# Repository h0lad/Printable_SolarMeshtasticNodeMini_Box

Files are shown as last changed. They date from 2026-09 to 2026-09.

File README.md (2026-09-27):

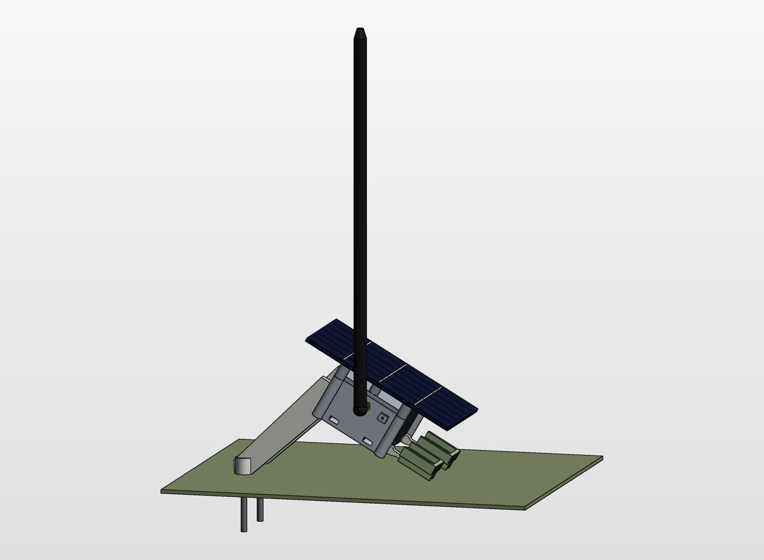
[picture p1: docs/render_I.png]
The box tilted on its two legs

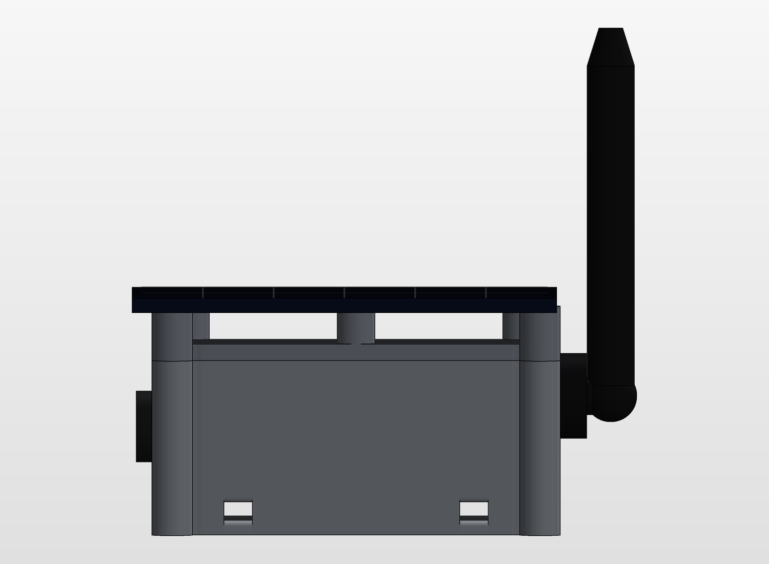
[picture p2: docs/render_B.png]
A section through the vent and the SMA bulkhead

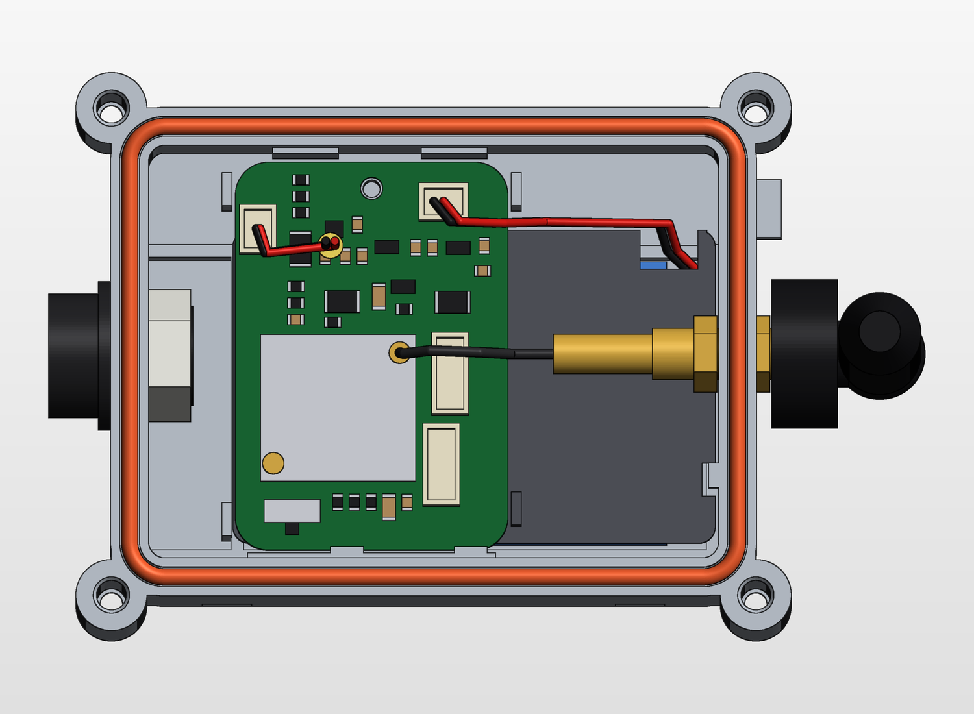
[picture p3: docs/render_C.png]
The top of the box, between the solar panel spacers

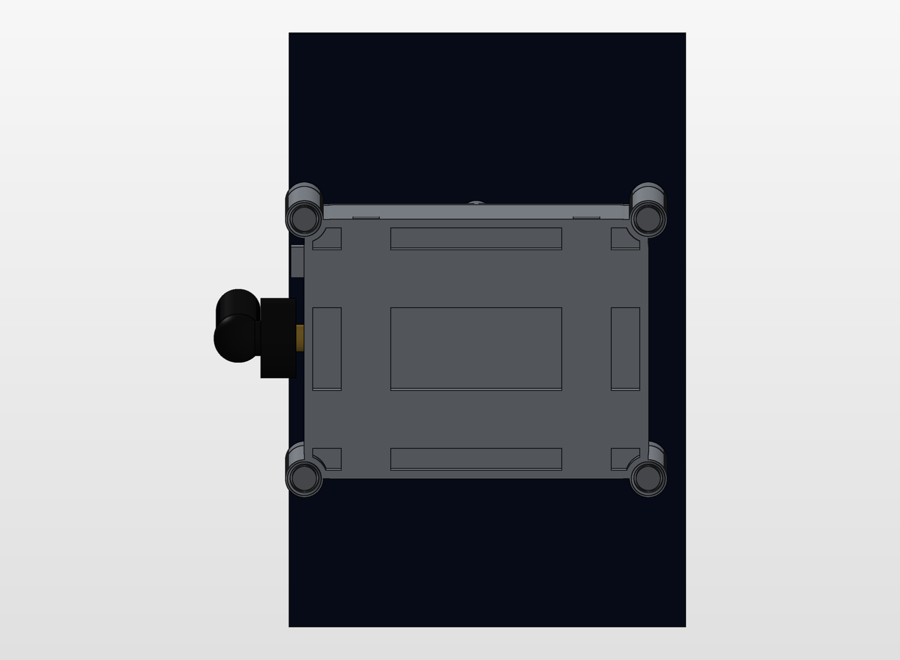
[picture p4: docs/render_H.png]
The underside, with the lashing tunnels and the floor relief


## Purpose

This box holds the SolarMeshtasticNodeMini node.

## Dimensions

The body is 78.2 x 59.2 x 40.5 mm, and the screw columns bring the footprint to 86.6 x 67.6 mm.

The solar panel and its spacers add 11 mm.

The inner cavity is 69 x 50 x 28 mm, and the vent chamber occupies x 59 to 69.

## Components to buy

- LiPo 103450 with a JST-PH lead, or LiPo 852040 with the adapter tray
- SMA bulkhead to U.FL, nose up to 20 mm, cable at least 90 mm
- ePTFE vent plug, thread 12 mm diameter and 10 mm long, head up to 20 mm, with its plastic nut
- Solar panel up to 135 x 90 mm, glued to the spacers with MS polymer
- 2 mm silicone O-ring cord, about 260 mm
- 4 M3x40 A4 screws, fitted from below, captive in a 2.7 mm neck, into 4 heat set inserts with a
  4.0 mm bore, 7 mm deep
- 1 M2.5x6 screw for the PCB, with a 2.1 mm pilot
- Cable ties 5 x 1.5 mm, or cord up to 3 mm, for the lashing tunnels

## Wind

The tipping speed comes from `tools/stability.py`. The stone sits in the ballast trays.

| setup | tips at | for reference |
|---|---|---|
| bare | 12.1 m/s | 44 km/h |
| 1 kg of stone in the trays | 14.5 m/s | 52 km/h |
| 2 kg of stone in the trays | 16.4 m/s | 59 km/h |

## Checks

The tools in `tools/` prove the numbers in this file. They need FreeCAD 1.0 with gmsh and ccx, and
every one of them writes a `.json` report beside itself.

| tool | what it proves |
|---|---|
| `design_rules.py` | the wall thickness, the holes, the gaps, the shell count, the build volume, and the collisions |
| `tolerance_mc.py` | every fit that has to go together, by Monte Carlo |
| `montage_simulation.py` | every step of the build order, over the full insertion travel |
| `clearance_probe.py` | the free radius around every fastener and nut |
| `stability.py` | the tipping speed, the hold-down force and the ballast mass |
| `thermal_lumped.py` | the internal temperature in the sun |
| `integrity_check.py` | the committed STEP files against a fresh run of the macro |

Run each one from `tools/`, as its docstring says.

## License

CERN Open Hardware Licence Version 2 - Strongly Reciprocal

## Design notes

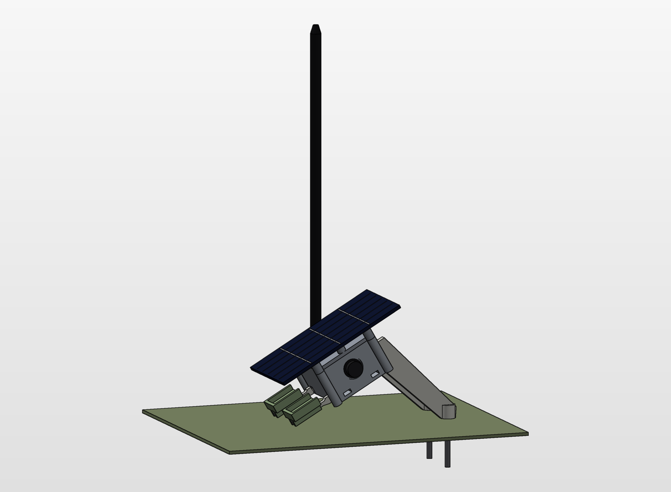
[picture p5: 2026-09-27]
docs/render_J.png

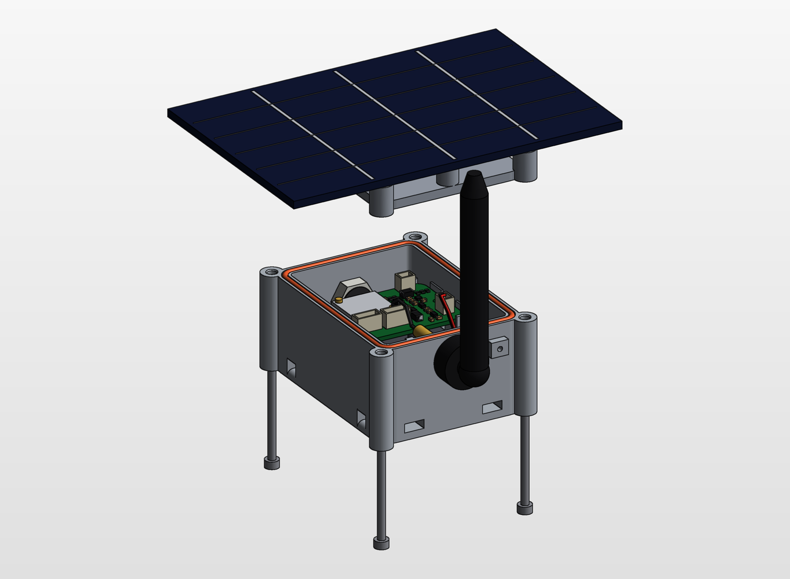
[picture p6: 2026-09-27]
docs/render_A.png

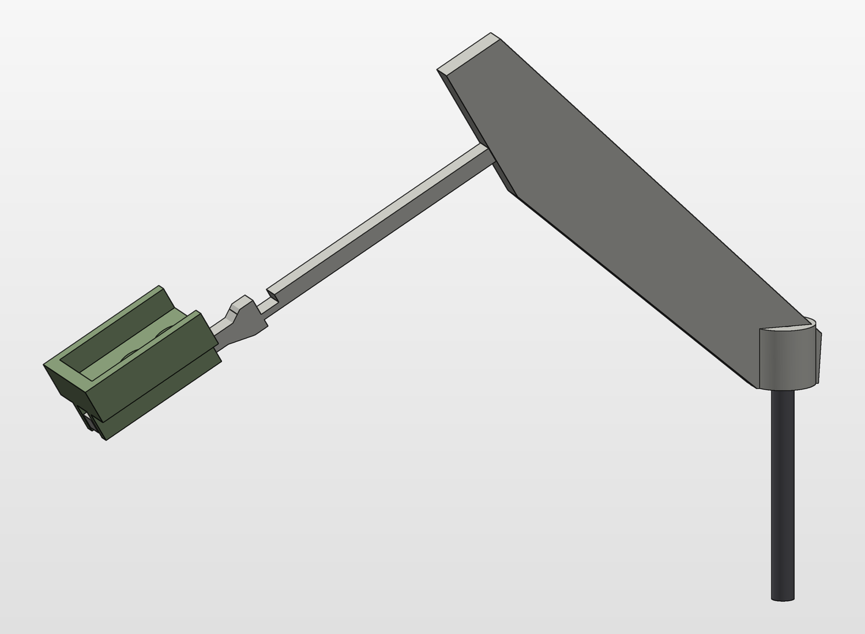
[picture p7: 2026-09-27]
docs/render_stand_fit.png

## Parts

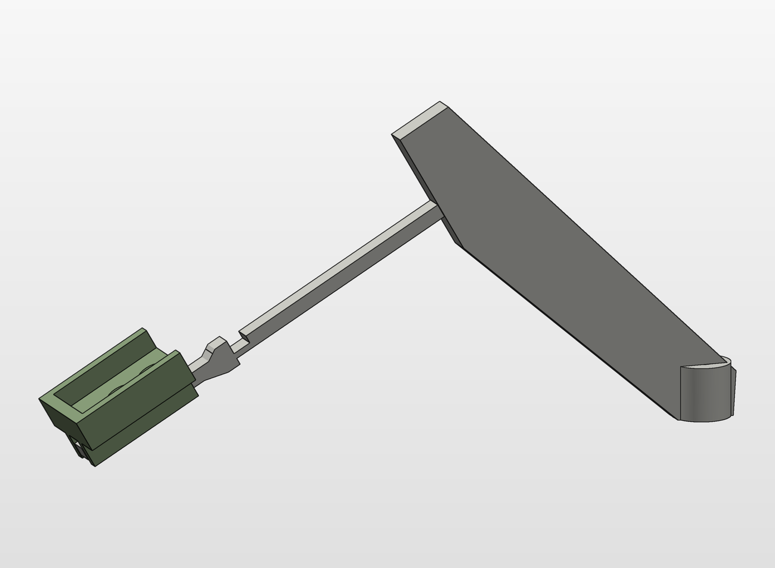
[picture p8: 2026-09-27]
docs/render_stand_parts.png

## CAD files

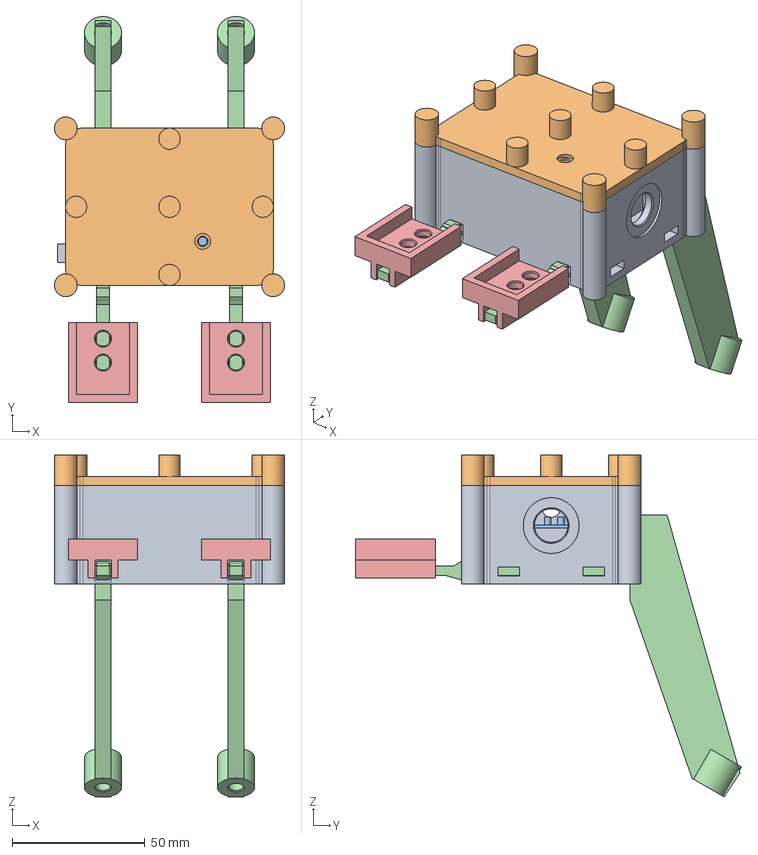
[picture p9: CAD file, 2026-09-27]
steps_stl/SolarMeshtasticNodeMini_assembly.step
86.6 x 145.2 x 128.6 mm

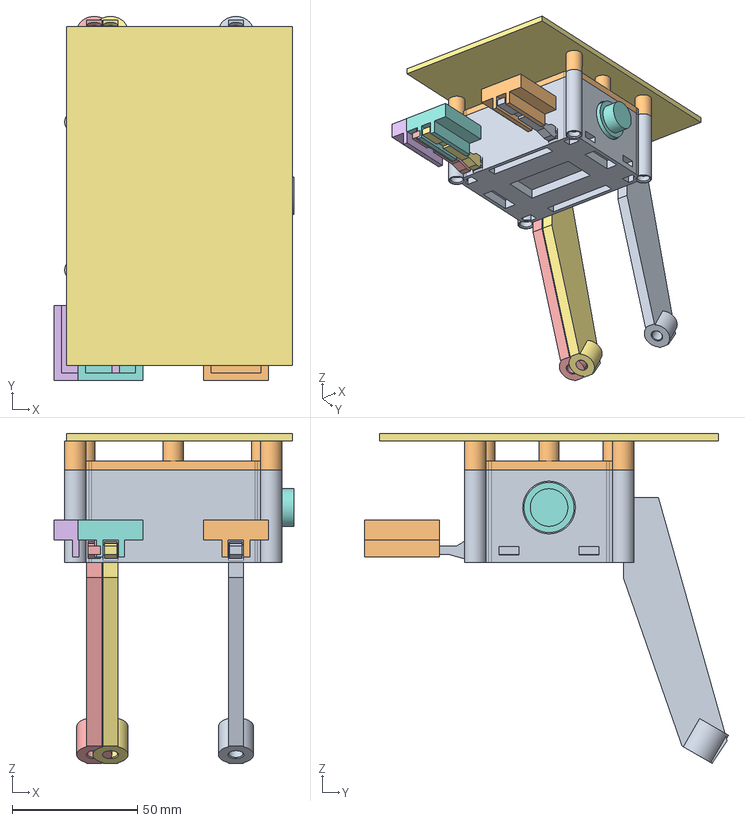
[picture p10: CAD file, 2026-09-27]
freecad/SolarMeshtasticNodeMini_Enclosure.FCStd
95.6 x 145.2 x 131.6 mm
base
lid
battery_plate
adapter_852040
stand_leg_x2
stand_tray_x2
stand_leg_1
stand_tray_1
stand_leg_2
stand_tray_2
PCB_dummy
parts_dummy
LiPo_103450_dummy
LiPo_852040_dummy
panel_135x90_dummy
vent_plug_dummy
vent_nut_dummy

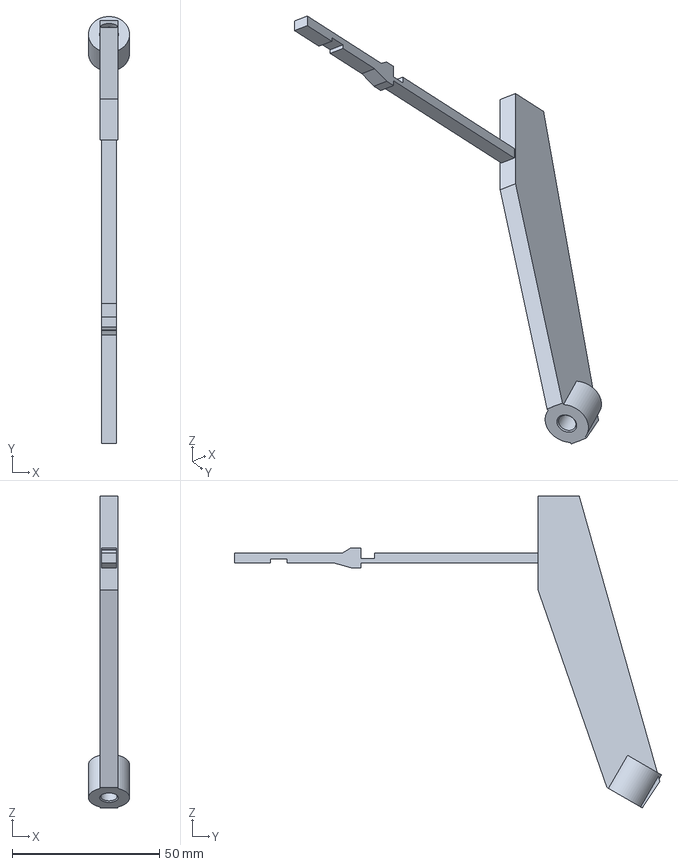
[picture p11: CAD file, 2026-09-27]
steps_stl/SolarMeshtasticNodeMini_stand_leg_x2.step
14.0 x 145.2 x 106.1 mm

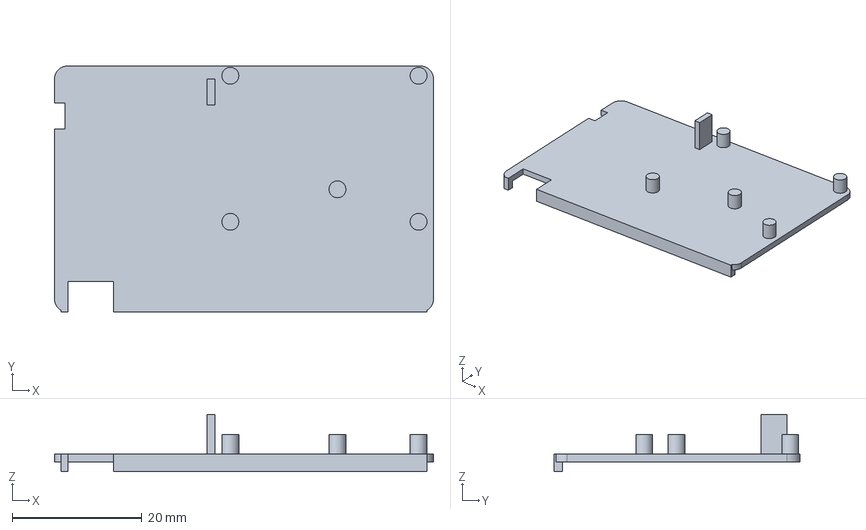
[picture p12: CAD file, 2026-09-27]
steps_stl/SolarMeshtasticNodeMini_battery_plate.step
58.4 x 37.9 x 8.79 mm

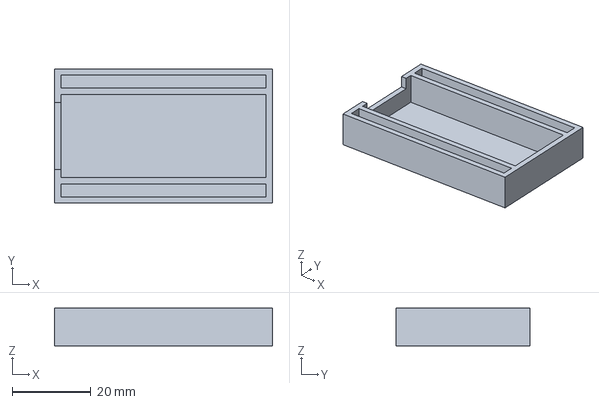
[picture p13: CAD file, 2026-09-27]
steps_stl/SolarMeshtasticNodeMini_adapter_852040.step
55.2 x 34.0 x 9.50 mm

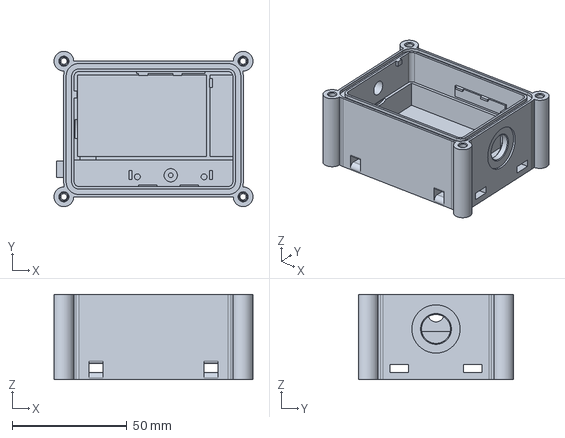
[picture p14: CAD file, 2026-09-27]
steps_stl/SolarMeshtasticNodeMini_base.step
86.6 x 67.6 x 37.0 mm

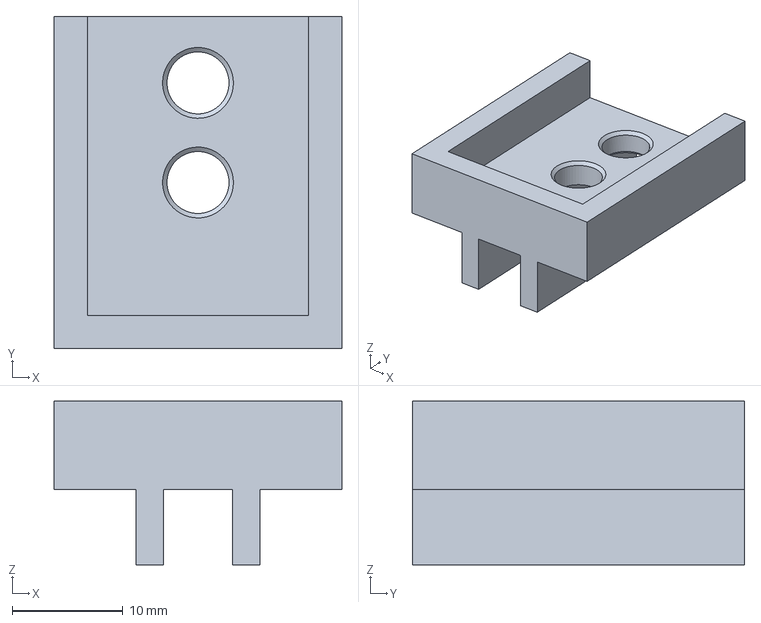
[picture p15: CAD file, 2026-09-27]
steps_stl/SolarMeshtasticNodeMini_stand_tray_x2.step
26.0 x 30.0 x 14.8 mm

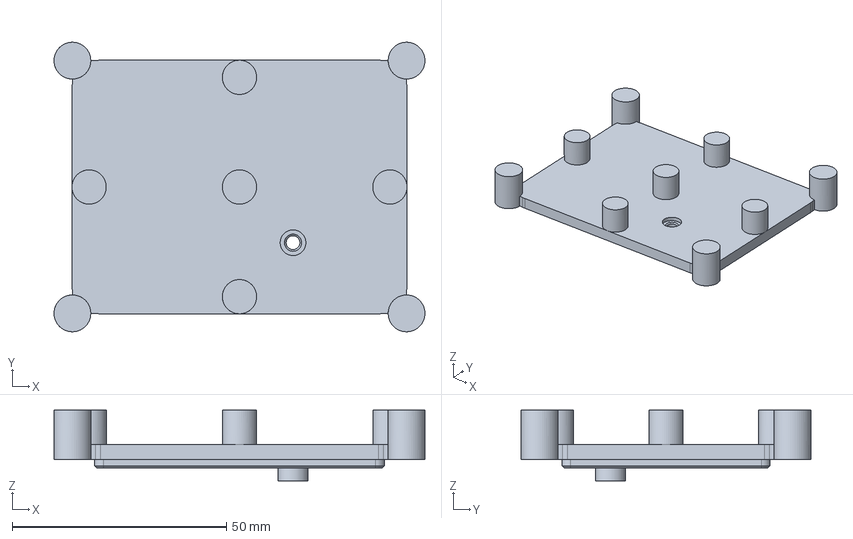
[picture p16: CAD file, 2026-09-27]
steps_stl/SolarMeshtasticNodeMini_lid.step
86.6 x 67.6 x 16.5 mm

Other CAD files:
steps_stl/SolarMeshtasticNodeMini_adapter_852040.stl
steps_stl/SolarMeshtasticNodeMini_base.stl
steps_stl/SolarMeshtasticNodeMini_battery_plate.stl
steps_stl/SolarMeshtasticNodeMini_lid.stl
steps_stl/SolarMeshtasticNodeMini_stand_leg_x2.stl
steps_stl/SolarMeshtasticNodeMini_stand_tray_x2.stl

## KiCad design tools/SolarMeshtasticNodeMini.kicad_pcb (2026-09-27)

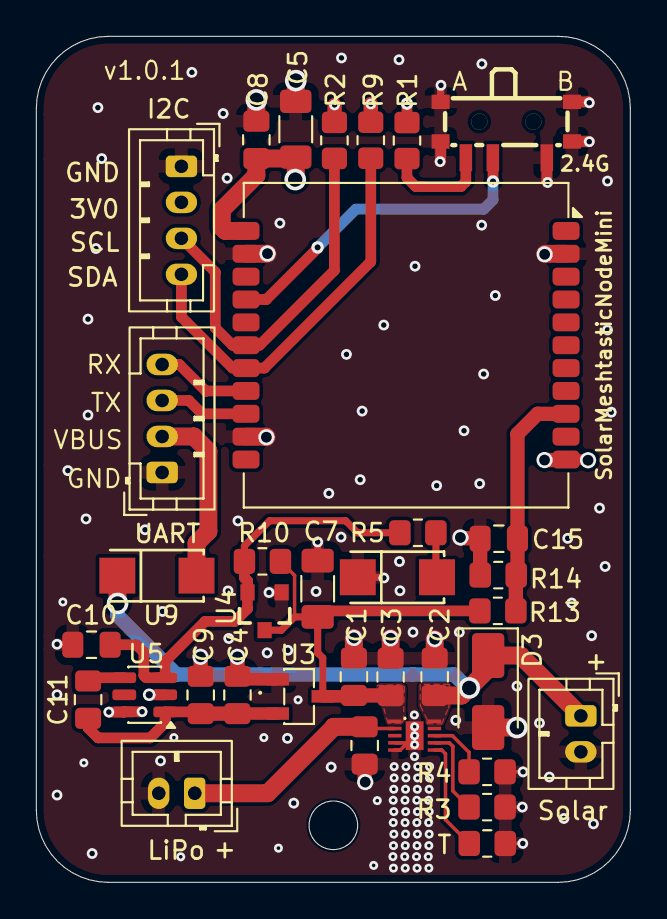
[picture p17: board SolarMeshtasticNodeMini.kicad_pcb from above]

Board: 4 copper layers, 33.0 x 47.0 mm, 36 parts (0 on the bottom side), 20 nets.

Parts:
C1, C4: 4.7uF; C_0805_2012Metric_Pad1.18x1.45mm_HandSolder
C2, C6, C9, C10: 1uF; C_0805_2012Metric_Pad1.18x1.45mm_HandSolder
C3: 10uF; C_0805_2012Metric_Pad1.18x1.45mm_HandSolder
C5: 47uF; R_1206_3216Metric_Pad1.30x1.75mm_HandSolder
C7: 1uF; C_1206_3216Metric_Pad1.33x1.80mm_HandSolder
C8, C15: 100nF; C_0805_2012Metric_Pad1.18x1.45mm_HandSolder
C11: 1nF; C_0805_2012Metric_Pad1.18x1.45mm_HandSolder
D3: SMAJ14A; D_SMA
H1: MountingHole; MountingHole_2.7mm_M2.5_ISO7380
J2: Conn_01x02_Socket; JST_PH_B2B-PH-K_1x02_P2.00mm_Vertical
J3, J5: Conn_01x04_Socket; JST_PH_B4B-PH-K_1x04_P2.00mm_Vertical
J4: Conn_01x02_Pin; JST_PH_B2B-PH-K_1x02_P2.00mm_Vertical
R1, R2, R9: 10k; R_0805_2012Metric_Pad1.20x1.40mm_HandSolder
R3, R10: 100k; R_0805_2012Metric_Pad1.20x1.40mm_HandSolder
R4: 360; R_0805_2012Metric_Pad1.20x1.40mm_HandSolder
R5: 470; R_0805_2012Metric_Pad1.20x1.40mm_HandSolder
R6: MF11-103; R_0805_2012Metric_Pad1.20x1.40mm_HandSolder
R13, R14: 1M; R_0805_2012Metric_Pad1.20x1.40mm_HandSolder
SW1: SSSS811101; SW-SMD_SSSS811101
SW2: SW_Push; SMA_L4.3-W2.6-LS5.1-RD
U1: BQ25185; SON40P220X200X80-11N
U2: HT-CT62; Heltec_HT-CT62
U3: HE9073A30MR; SOT-23-3_L2.9-W1.6-P1.90-LS2.8-BR-CW
U4: APX803L05-32SA-7; SOT23-3
U5: TPS22917DBV; SOT-23-6
U9: SS26_C5350986; SMA_L4.3-W2.6-LS5.1-RD

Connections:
+3V0: C5.2, C8.2, J5.2, R1.2, R2.2, R9.2, U2.11 (EN), U2.12 (VDD), U5.6 (VOUT)
/ADC_LOAD: C15.1, R13.2, R14.1, U2.9 (GPIO1)
/ESP32_BOOTLOADER_MODE_1: SW1.2, U2.15 (GPIO9)
/I2C_SCL: J5.3, R2.1, U2.17 (GPIO18_DN)
/I2C_SDA: J5.4, R9.1, U2.18 (GPIO19_DP)
/U_RX: J3.4, U2.19 (GPIO20_RXD)
/U_TX: J3.3, U2.20 (GPIO21_TXD)
/VBUS: C2.2, D3.1 (A1), J2.1, U1.10 (IN), U9.1 (K)
/VLIPO: C6.1, J4.1, U1.2 (BAT)
/VLOAD: C1.1, C3.2, C7.2, R10.1, R13.1, U1.1 (SYS), U3.2 (VIN), U4.3 (Vcc)
/VOUT: C4.1, C9.1, C11.1, U3.3 (VOUT), U5.1 (VIN)
/nReset: C10.2, R5.2, R10.2, U4.2 (nReset), U5.3 (ON)
GND: C1.2, C2.1, C3.1, C4.2, C5.1, C6.2, C7.1, C8.1, C9.2, C10.1, C15.2, D3.2 (A2), J2.2, J3.1, J4.2, J5.1, R3.2, R4.2, R6.2, R14.2, SW1.1, SW1.4, SW1.5, SW1.6, SW1.7, SW2.1, U1.4 (/CE), U1.5 (GND), U1.11 (GND), U2.2 (GND), U2.13 (GND), U2.21 (GND), U3.1 (GND), U4.1 (GND), U5.2 (GND)
unnamed: J3.2, U9.2 (A)
unnamed: R1.1, SW1.3
unnamed: R5.1, SW2.2
unnamed: R3.1, U1.7 (ILM/VSET)
unnamed: R4.1, U1.8 (ISET)
unnamed: R6.1, U1.6 (TS/MR)
unnamed: C11.2, U5.4 (CT)

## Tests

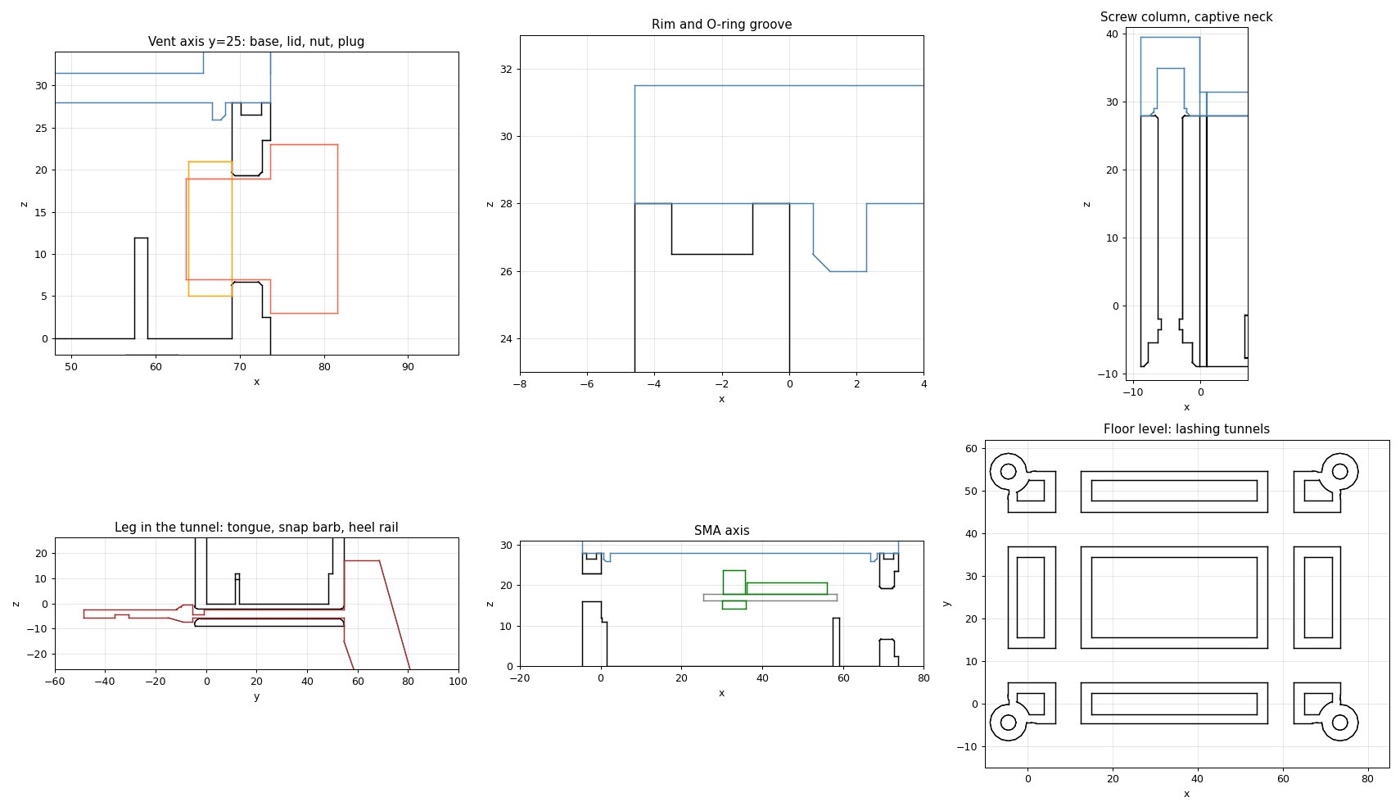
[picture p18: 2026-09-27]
docs/validation_sections.png
